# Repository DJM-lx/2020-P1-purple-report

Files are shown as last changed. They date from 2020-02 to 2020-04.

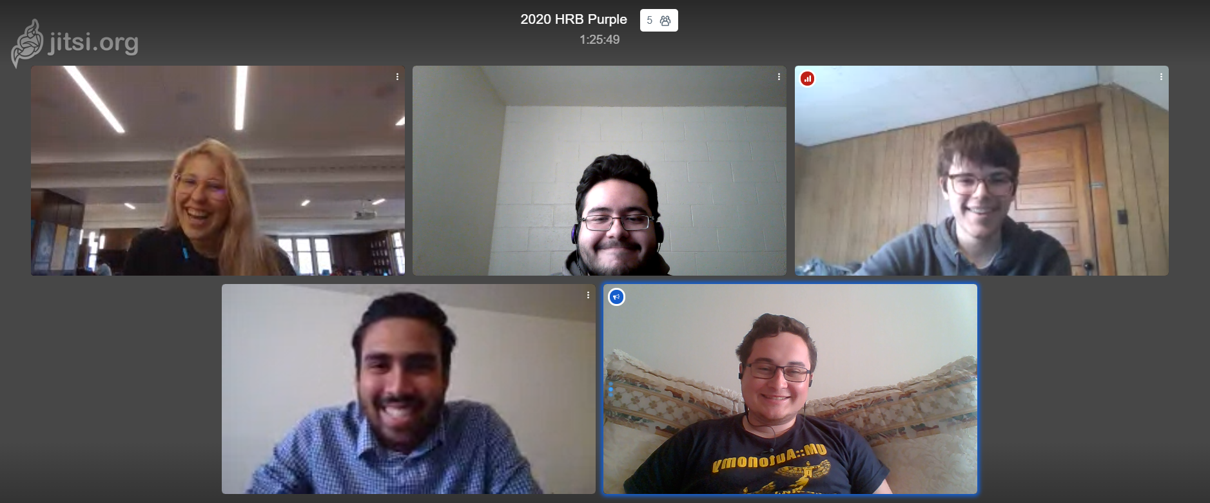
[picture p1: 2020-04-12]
2020-P1_Purple-photo.png

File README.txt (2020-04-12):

This file contains all the necessary resources to reproduce our project for P1-2020

///////////////////////////////////////////////////////////////////////////////

COPYRIGHT.txt - A copyright provision detailing the allowed use of our project resources

2020-P1-Purple-photo.png - photo of the team

2020-P1-purple-team-resources.pdf - a compiled list of resources that guided us in the brainstorming phase

2020-P1-purple-brainstorming.pdf - A PDF of our initial brainstorming presentation given at the beginning of the project cycle

2020-P1-purple-final.pdf - The final report detailing and discussing the results of the project deliverable

src - A folder containing our source code and the details for its use
	-scorpionMasterControl.py - our python script that sets up sensor and waypoint data
	-scorpionPlans.py - our python script for contains plans for autonomous movement
	-scorptionReIX.py - our python script for translating simulated motion to robotic movement
	-scorpionSimIS.py - our python script for simulated motion

howto- A folder containing our how-to documentation to recreate the robot mechanically
	-2020-P1-Purple-howto.pdf the how-to guide to recreate the robot step-by-step
	-3D_Print.zip - the 3d printing files for 3d printed parts we used
	-CadFiles.zip - the cad files for 3d printed parts 
	-Images.zip - the cad images of our robot and robot parts
	-Laser_cutting.zip - files for laser cutting the base

brstm- Source files we used for our brainstorming phase
	- 2019 Red Team's Cad files for their mechanum wheels

////////////////////////////////////////////////

Team Members:

Madi DeVore - devore@umich.edu

David Marsh - djmarsh@umich.edu

Matt Maurer - mlmaurer@umich.edu

Christian Soto - cbsoto@umich.edu

Ragav Subramanian - sragav@umich.edu

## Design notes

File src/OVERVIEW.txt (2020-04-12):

scorpionMasterControl imports from robotSimIX and waypointShared to setup the sensor and waypoint data, sets up the arena

scorpionPlans contains the plans we used to create our autonomous movement

scorpionReIX translated the key presses that moved the simulated robot into moving the motors of the physical robot

scorpionSimIX is the mapped events for the simulated robot. Creates translational movement using the arrow keys and 'A' to start 
autonomous mode

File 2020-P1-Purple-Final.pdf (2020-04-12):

### EECS 464 Project 1

Purple Team: Madi DeVore, David Marsh, Matt Maurer, Christian Soto, Ragav Subramanian April 12, 2020

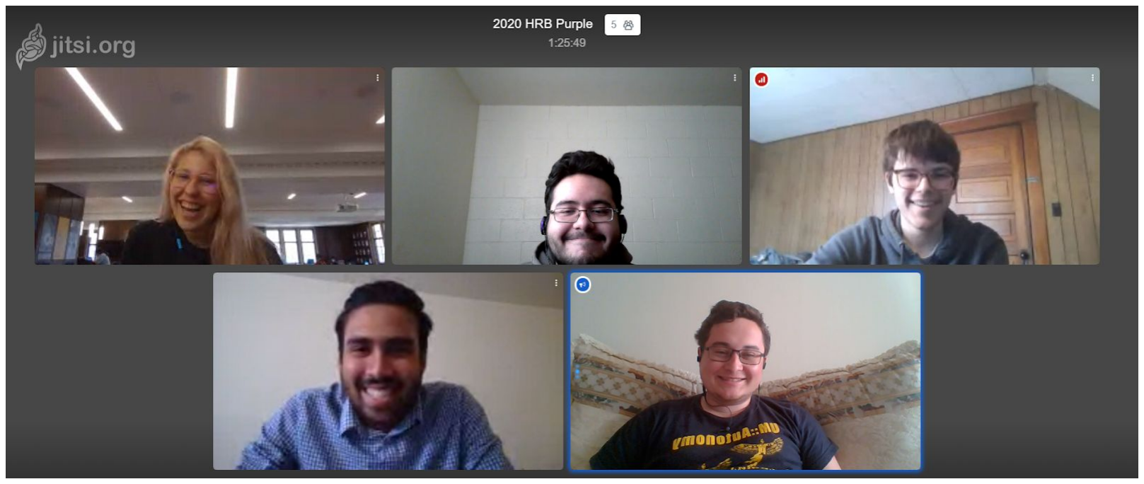
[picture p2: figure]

EECS 464 Project 1

1

Background

3
Project Tasks

3
Arena Layout

3
Research and Design Process

3
Mecanum Wheeled Design 1

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
Moving Turret

5
Final Design

5
Hardware

5
Software

6

P-Day Results

6
Pass/Fail Requirement

6
Overview of Teams performance for each arena

7

Discussions

7
Overall analysis

7
Individual Team Designs

7
Purple

7
Blue

8
Maize

8
Green

9
Red

9
Future Improvements | 10
Hardware | 10
Software | 10
Update moving between waypoints | 10
Modify the recovery plan | 10

### Background

Project Tasks
Our task goals and requirements were listed in the task specifications for Winter 2020 EECS 464 Project 1. Our task was to design and build a physical and simulated robot that could traverse an arbitrarily sized track with arbitrarily placed waypoints while maintaining the orientation of the direction of a mounted laser. In addition, the robot’s movement to and between the waypoints were to be achieved with and without human interference. Due to recent events at the time this project was attempted, any goals and requirements involving the physical robot were considered omitted from the task specifications. The pass-fail criteria for meeting the task goal were as follows:
- Robot stays in the arena, with robot tag within 1m vertically of the floor
- Robot reaches the final waypoint within 15 minutes
- Laser never illuminates in a direction with a negative Y component

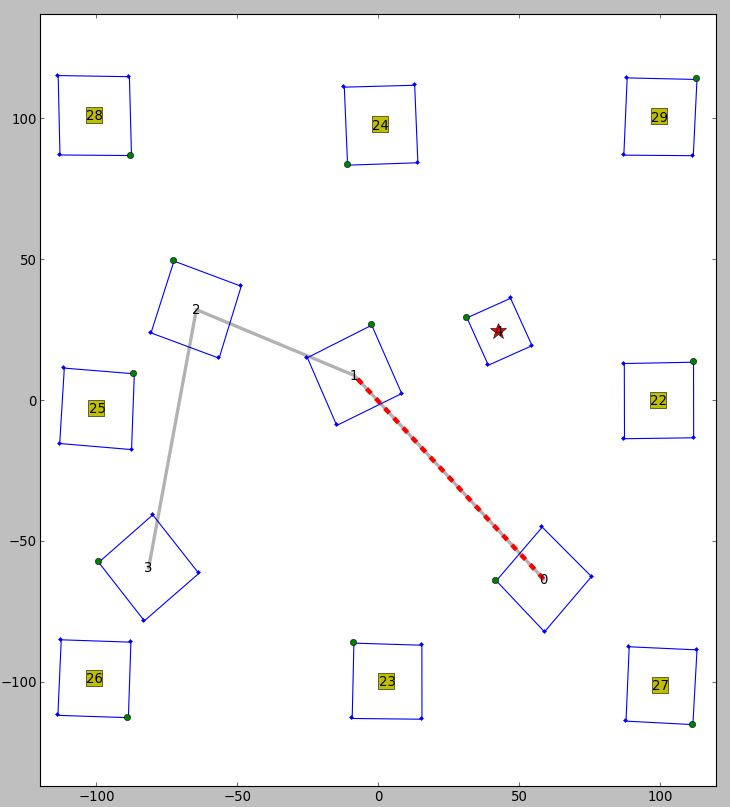
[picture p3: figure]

Arena Layout
The arena in which the robot operates is a 2m x 2m square delineated by 8 barcodes or tags as they’re seen in the virtual modelling. All tags are square and the same size. The waypoints are also modelled using tags and the location of the robot is tracked using its own tag. In order to successfully reach a waypoint the robot’s tag must be within a tag’s radius of the waypoint tag. Since we switched to modelling the arena virtually the physical dimensions are arbitrary as we now use x and y coordinates.

Research and Design Process
Before beginning the construction of the robot, we considered multiple design alternatives. This section describes the three alternatives we showcased in our brainstorming presentation. (https://wiki2.eecs.umich.edu/hrb/index.php/File:2020-P1-purple-brainstorming.pdf)

Mecanum Wheeled Design 1
Design 1 used mecanum wheels similar to 2019 Red Team. (https://wiki2.eecs.umich.edu/hrb/images/1/1a/2019-P1-red-final-GRADED.pdf) We considered using three pairs of mecanum wheels and continuous rotation (CR) modules attached to the bottom of our proposed triangle base. A mecanum wheel, shown in Figure 2, is a wheel that has cylindrically-shaped rollers mounted around its circumference at a 45 degree angle to the axis of rotation. A mecanum wheel has independent motion relative to the others in the system, and the combination of all these different motions can be vectored into cardinal directions relative to the system, shown in Figure 3. A more detailed explanation can be found at Wikipedia’s Mecanum Wheel, (https://en.wikipedia.org/wiki/Mecanum_wheel) and a YouTube demo can be found here. (https://www.youtube.com/watch?v=o-j9TReI1aQ)

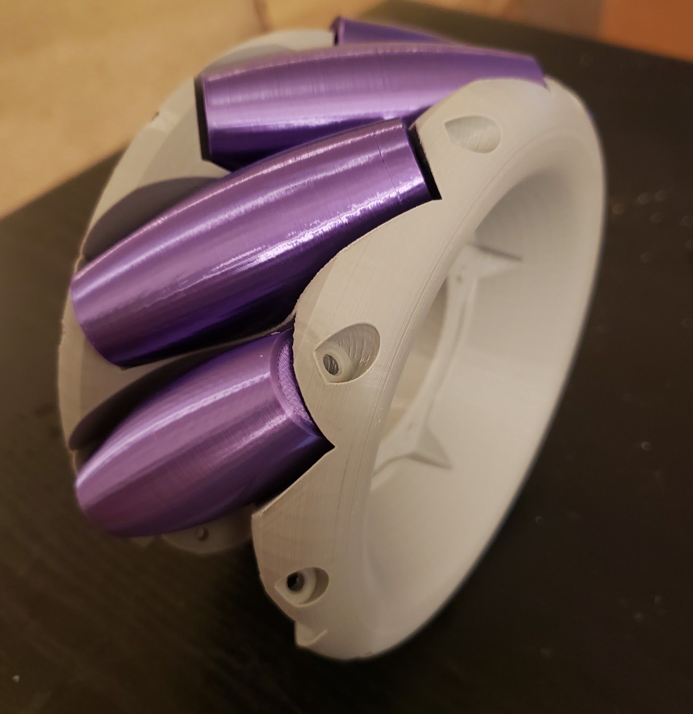
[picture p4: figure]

Wheeled Design 2

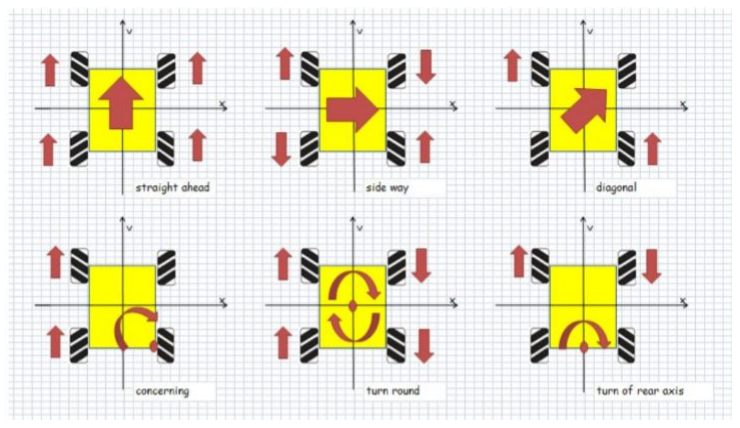
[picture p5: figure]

We considered attaching a U-bracket module to the end of a CR module. A drive wheel attached to the CR module could be lifted off the ground using the U-bracket module, shown in Figure 4. If we had two pairs of motors in this configuration, mounted orthogonal to each other, we could drive anywhere in the plane without rotating the robot. We planned on putting ball castors, shown in Figure 5, on the bottom of the robot so that the base supporting the motor modules could glide in both directions.
We did not end up pursuing castors on the base because we were concerned that the robot would turn on the castors. However we did use the CR module mounted on the end of the U-bracket module for our final design.

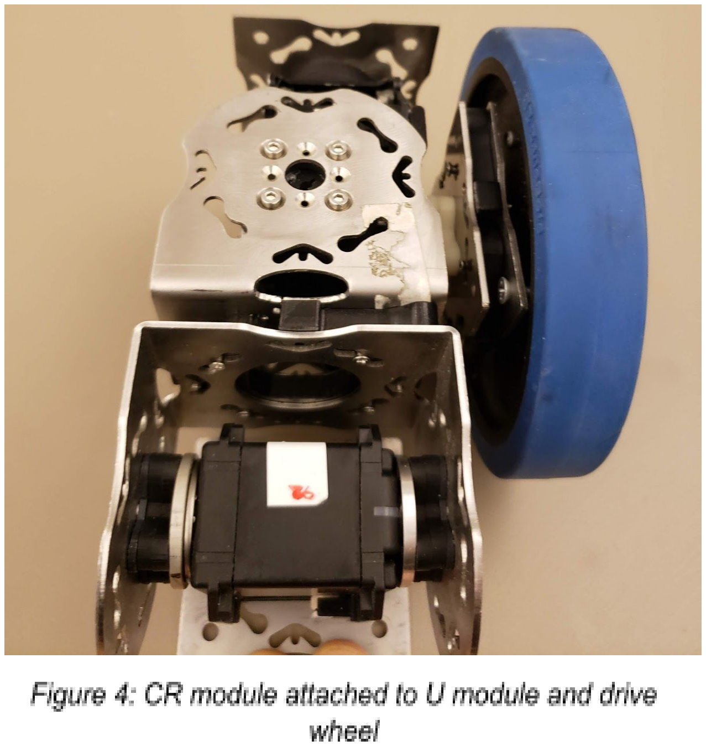
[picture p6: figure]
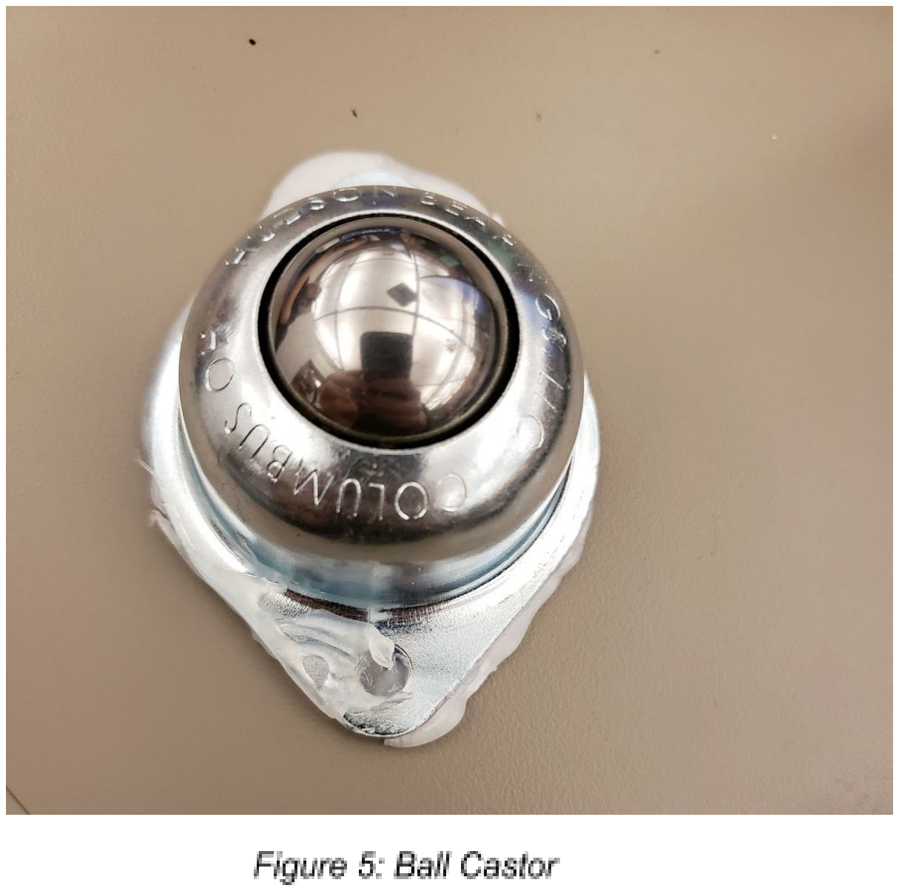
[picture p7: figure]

Moving Turret
This Moving Turret Design was an experimental idea that was not based off of any previous team’s design. The basis of the design was to take a lot of the heavy work off of any software control system for maintaining the turret consistently in the +x-direction. The robot was designed to have a rod that is freely held using bearings through the center of the robot chassis. This central rod would hold the turret on top and have a castor wheel on the bottom. This pivotal rod would allow the turret to remain focused in +x-direction as we pivot the robot to turn, the rod would not rotate due to the low-friction skateball bearings that would connect the central rod to the chassis. However, we did not pursue this idea as it was quite experimental and if the frictionless effect of the bearings did not hold up, the mechanical design would be for nothing.

Final Design

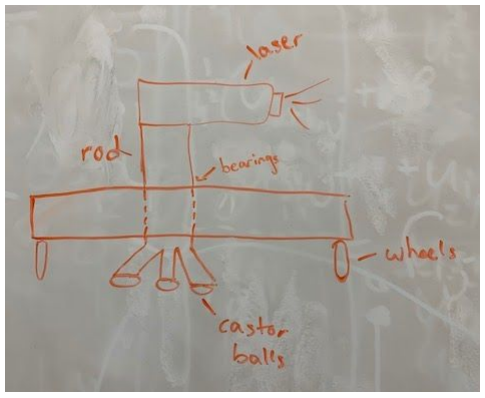
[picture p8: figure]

The project moved to a simulation after completing demos 1 and 2 due to the cancelation of in-person lectures.

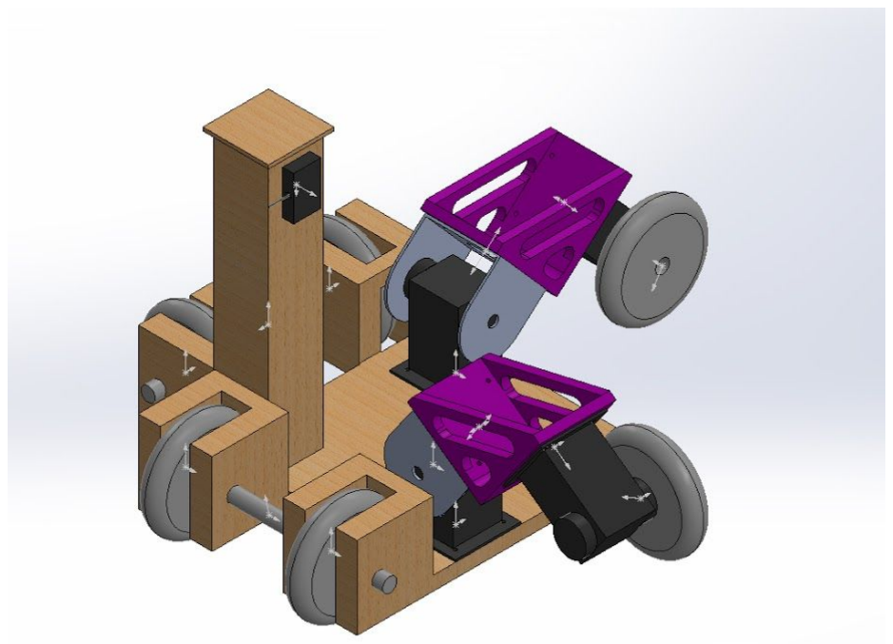
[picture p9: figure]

Hardware
Our final design was essentially two tricycles in orthogonal
directions. By lowering one of the two U-bracket modules, we could tip the base of the robot until only the three wheels oriented in that direction were touching the ground. Then, the robot moved in a straight line by rotating a CR module attached to the end of the U-bracket module.
The robot was able to move continuously in +- X and +- Y with minimal rotation in the z direction. The physical robot was abandoned before we were able to gather quantitative data.

Software
The software we created can be found in the Purple Team How-To Directory. (https://wiki2.eecs.umich.edu/hrb/index.php/File:2020-P1-purple-howto.zip) We chose to use a Python program to control the simulation, utilizing the robotSimIX library provided and a scorpionSimIX file of our own. Our control program mimicked the translational motion of the mobot we designed allowing it to go left, right, forwards, and backwards without turning. When in manual mode the program created an event handling system to handle keyboard presses as shown in Table 1 so that it would move when the corresponding buttons were pressed. Upon pressing ‘A’ the software would start the autonomous plan which would calculate the distance from the first waypoint to the next and attempt to move that distance in the x and y directions. If the waypoint was missed then it would spiral from where the simulated robot moved to until it reached the next waypoint. The worst case of the spiral feature would be to extend the spiral to spanning the entire arena.
Key | Left Arrow | Right Arrow | Up Arrow | Down Arrow | ‘A’
Simulated Action | Move left | Move right | Move forward | Move backwards | Start autonomous mode

### P-Day Results

P-day consisted of 10 different arenas that each team attempted to complete within the time constraints of the class period. This averaged to about 10 minutes per arena. Each arena had a different seed that would randomize the waypoints’ locations.

Pass/Fail Requirement
Due to the project moving to a virtual format the pass/fail requirement was changed. The conditions relating to the physical movement of the robot were dropped and now each team needed to reach the final waypoint in under 15 minutes. Each team completed the pass/fail requirement during P-Day and were able to submit multiple runs with completed arenas. Most teams were able to complete all 10 arenas, but Purple and Maize ran into technical difficulties and were only able to submit 5 arenas.

Overview of Teams performance for each arena
Each team had the capability to move their robot manually to the final waypoint. Maize and Red teams chose to manually move their robots and not attempt autonomous mode. Green team attempted autonomous mode but failed and then drove their robot manually to the final waypoint. Purple team attempted autonomous mode but ran into problems with correctly generating the randomized arena. Purple team managed to successfully complete a couple of arenas in autonomous mode but did not have enough time to attempt all arenas. Blue team was the most successful attempting autonomous mode for each arena and managed to hit all of the waypoints. A breakdown of how each team performed in each arena is given in Table 2.

Team | Arena 0 | Arena 1 | Arena 2 | Arena 3 | Arena 4 | Arena 5 | Arena 6 | Arena 7 | Arena 8 | Arena 9
Maize | ---- | 2/3 | M | ---- | ---- | M | ----- | M | M | -----
Red | M | M | M | M | M | M | M | M | M | M
Green | AA | AA | AA | AA | AA | AA | AA | AA | AA | AA
Purple | AA | ------ | AS | AS | AS | ----- | AS | ----- | ----- | ------
Blue | AS | AS | AS | AS | AS | AS | AS | AS | AS | AS

Maize team had problems getting their robot to find the first waypoint, their missing trials corresponded to the runs where they were unable to locate the first waypoint and got stuck. Maize team was able to successfully reach 2 of 3 waypoints in Arena 1. Purple team’s missing trials were from running out of time during P-Day and also from running the arenas before realizing that we were incorrectly randomizing the waypoints. The data produced from those runs correspond to the same waypoints given to us to practice with.

### Discussions

Overall analysis
Blue team was the only team to successfully use autonomous mode for every arena. Green and Purple also attempted autonomous mode but were either unsuccessful or sometimes successful. Maize and Red used manual mode for each arena.

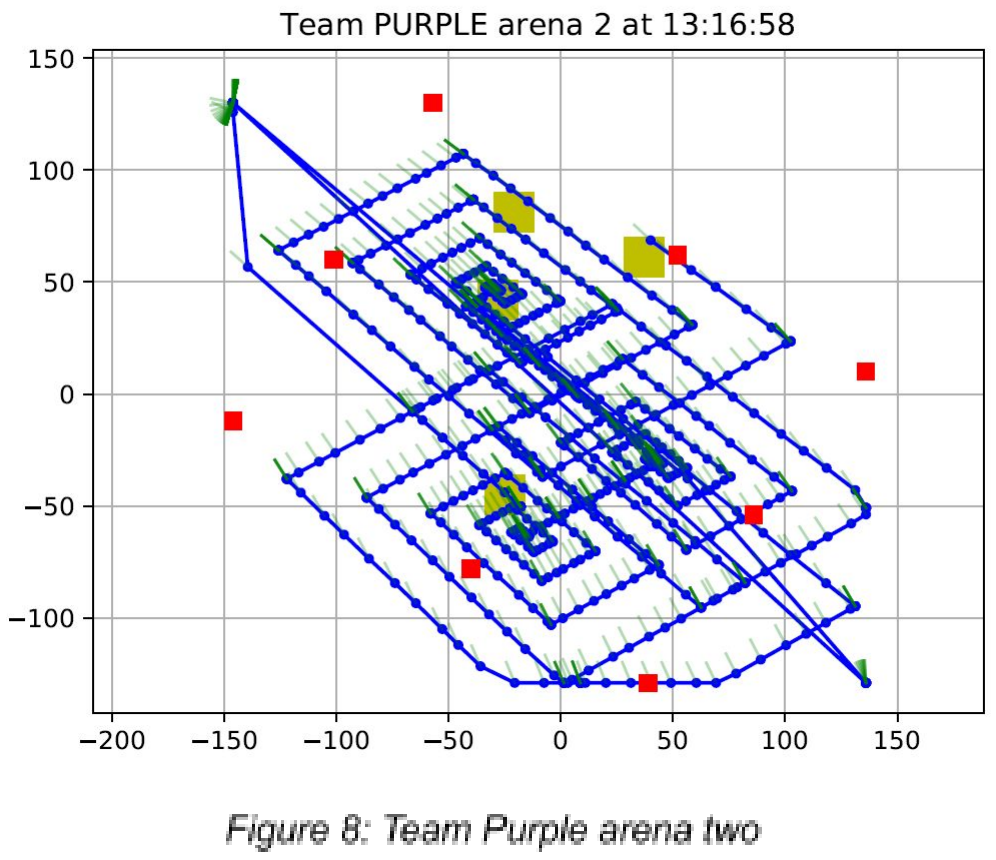
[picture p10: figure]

Individual Team Designs

Purple
Once we fixed the problem with our code not correctly generating new arenas we had successful autonomous trials. Since it took us about half an hour to work out why our code wasn’t functioning and about 20 minutes more to debug the problem we did not have enough time to run all the arenas. This bug came up because we created our own class that inherited some of Professor Revzen’s code, but it was not updated when new software updates were released. In the arenas we did have time to redo we had originally run them without regenerating new waypoints so they all had waypoints corresponding to those of the practice arena. Our simulation moved translationally. Once we drove to the first waypoint we would assume that the waypoint was our starting location and would calculate what y and x distances we would need to travel in order to reach the next waypoint. If the robot missed the waypoint it would spiral until it hit the next waypoint. In the visualization generated for arena 2 we missed the waypoint three times so there are three different spirals.

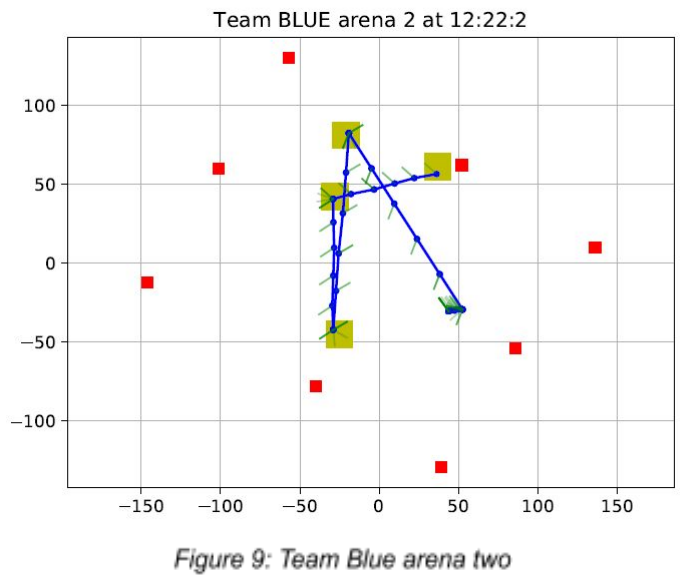
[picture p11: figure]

Blue
Blue team had a working autonomous program. They were able to reach all waypoints in all maps. Their program used a particle filter and attempted to drive directly to each waypoint. In the event that the robot missed the waypoint, it entered a scanning recovery procedure. They were able to finish 5 of the 9 maps directly without using the recovery procedure.

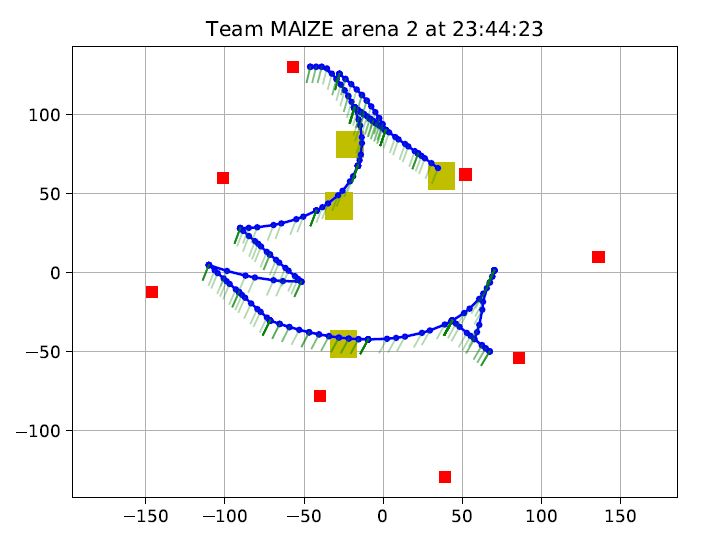
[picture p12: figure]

Maize
Maize team had computer hardware issues. They were unable to stream video and run the simulation smoothly at the same time. They drove manually to the waypoints. Their control system relied on needing to constantly reorient the arena. The more their simulated robot rotated the less they were able to control it. They used a spiralling recovery strategy that would swing the “arm” of the robot while driving it forwards and backwards to form a spiral.

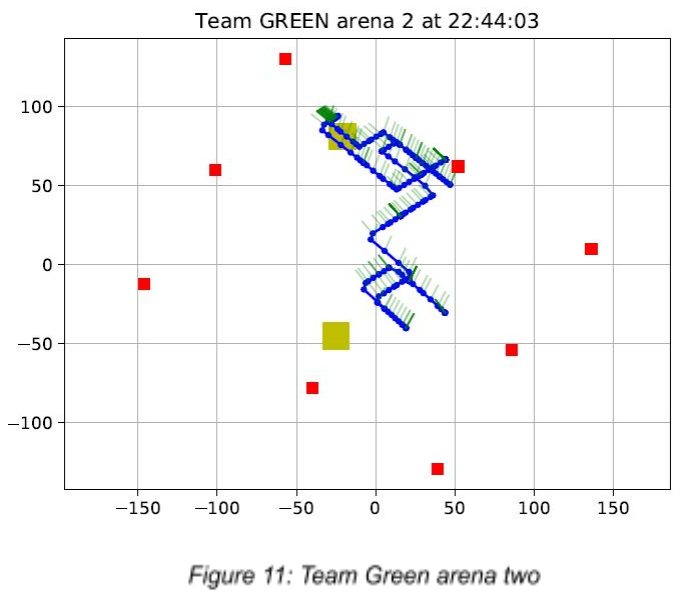
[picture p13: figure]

Green
Green team’s autonomy did not work. They drove to the waypoints manually. Their attempt at autonomous mode resulted in their robot veering off in the opposite direction of the waypoint and continuing indefinitely. Their strategy for recovering their robot during autonomous mode was to keep a history of their movements and backtrack if it missed the waypoint.

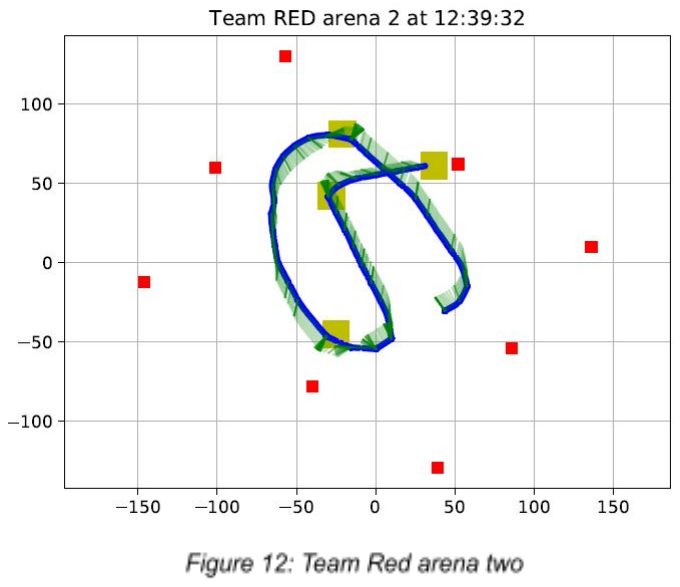
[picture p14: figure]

Red
Red team had their laser pointer pointing in the wrong direction. They drove to all the waypoints manually. They did not attempt to do autonomous mode and had no planned recovery strategy if their robot was to go off course. Their movement used a continuous position estimation by using a particle filter. Their simulation was able to rotate towards the direction they wanted to move and then advance in a line towards it.

Future Improvements

Hardware
The passive wheels on our robot were able to rotate independently from each other because they were both free on the axle. If the passive wheels were fixed to the axle and instead the axle spinned freely it could prevent the robot from rotating.

Software

Update moving between waypoints
Our robot moved in consistent steps when in manual mode, but when run in autonomous mode we had trouble calculating how many steps to use in each direction to reach our goal. Often the robot would overshoot or not move far enough in the x and y directions and would have to resort to spiralling to find the next waypoint. In the future we could improve our software design by making the movement between waypoints more precise and relying less on spiralling in order to reach the next waypoint.

Modify the recovery plan
Our recovery plan would be to just have it spiral until it reached the goal. In order to make this more effective we could add in counters to help us keep track of if we were more likely to over or undershoot or goal. Using this we could either backtrack or take an additional step before we start the spiral so that it wouldn’t need to spiral for very long. Additionally, a smaller step size might help prevent the robot from overshooting waypoints.

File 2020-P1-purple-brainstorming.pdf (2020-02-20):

# P1 - Brainstorming

## Purple Team: Madi DeVore, David Marsh, Matt Maurer, Christian Soto, Ragav Subramanian

# Overview

Each robot is required to reach a sequence of waypoints in a specified order while keeping a laser pointer oriented along the positive Y axis. Position of the robot, waypoints, and laser is given by a computer vision system provided by the instructor.

# Pass/Fail Criteria

1. Robot stays in the arena, with robot tag within 1m vertically of the floor
2. Robot reaches the final waypoint within 15 minutes
3. Laser never illuminates in a direction with a negative Y component

* if a team feels they might not meet the pass/fail criteria they may manually drive their robot to the final waypoint and forfeit the competition

# Design 1 - Mecanum Wheeled

This design utilizes omnidirectional mecanum wheels for the movement of the robot. It would have three rotational dynamixel modules mounted to the bottom surface of the chassis, and each module would rotate a mecanum wheel. The laser would be mounted in a constant orientation.

The robot and laser would face the same direction during the task, and different rotations of the dynamixel modules would result in the sufficient x- and y-motion without needing to rotate the robot.

Another variation of this design would be to use four mecanum wheels (two sets of mirrored pairs) with a similar design structure.

# Design 1 - Mecanum Wheeled

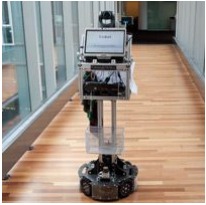
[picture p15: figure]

PROS:

- Body points in same direction
- 2019 Red Team (https://wiki2.eecs.umich.edu/hrb/images/1/1a/2019-P1-red-final-GRADED.pdf) made 3 mecanum wheeled robot that we can use as a basis

CONS:

- Mecanum wheel is difficult to build
- Slightly complex wheel movement

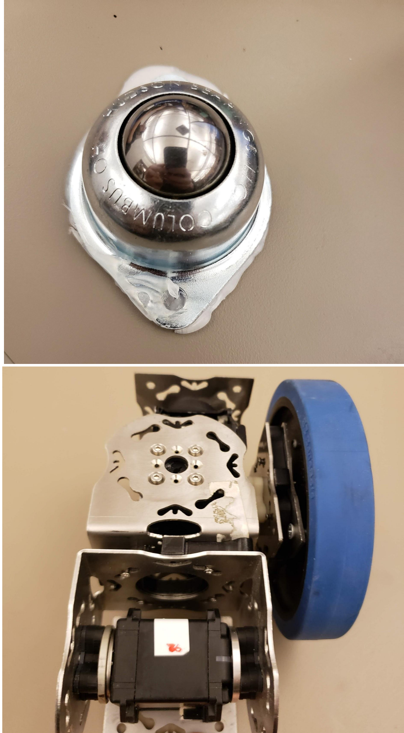
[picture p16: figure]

# Design 2

Rectangular base that slides on 4 castor balls

To move in Y:

A u-bar module mounted on the back of the base lowers two wheels driven by a continuous module

To move in X:

An identical mechanism is mounted on the left or right of the base

# Design 2:Pros and Cons

Pros:

- Separate systems for x and y motion help with holonomic motion

Cons:

- Asymmetrical weight distribution

# Design 3: Moving Turret

Two wheel based tower

Consists of laser on servo placed at top of tower

Laser will maintain aiming at the +y - direction and will adjust when turning using a PID controller

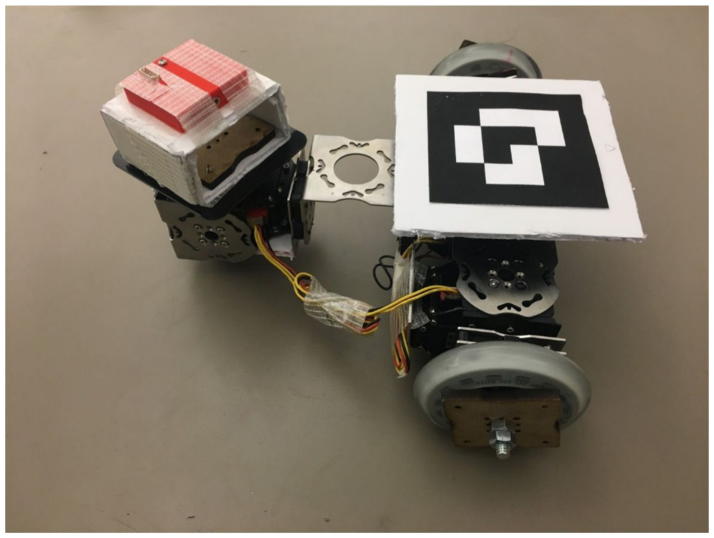
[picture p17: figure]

Inspired by 2018 Green team except laser mounted on top

# Design 3: Pros and Cons

Pros:

- Simple Mechanical Design
- Easy Mechanical Construction

Cons:

- May be challenging to work with PID controller
- Servo displacement error compounds

# Design 3.1: Moving Turret + standalone laser

Iteration of Moving Turret

Replace mounted servo with the laser on a rod that extends through chassis and stands on 3 legs with caster balls

-Minimum Friction bearings used to prevent rotation of servo mount

Lubricant may be used to ensure little to no friction between laser stand and chassis

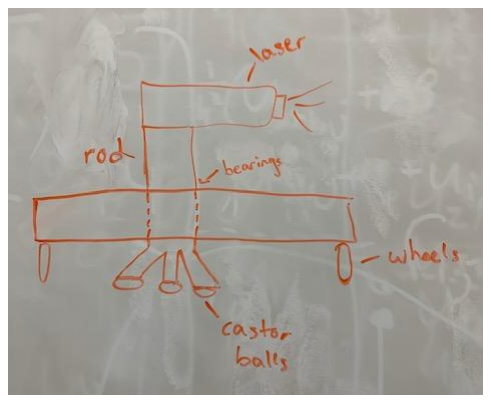
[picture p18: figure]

# Design 3.1: Pros and Cons

Pros:

- Simple Mechanical Movement
- Easy Mechanical Construction

Cons:

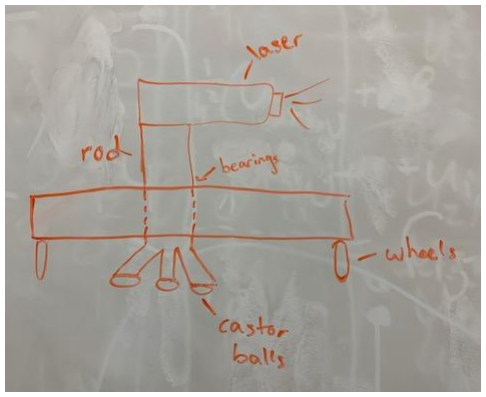
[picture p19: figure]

- Difficult to get rod to remain in place and “frictionless” bearing
- No control scheme

# Team Skills and Projected Roles

Madi: Mechanical design and testing

David: Mechanical design and construction

Matt: Prototyping and construction

Christian: Programming, Simulated Robotics

Ragav: Programming and Mechanical construction

# Workplan

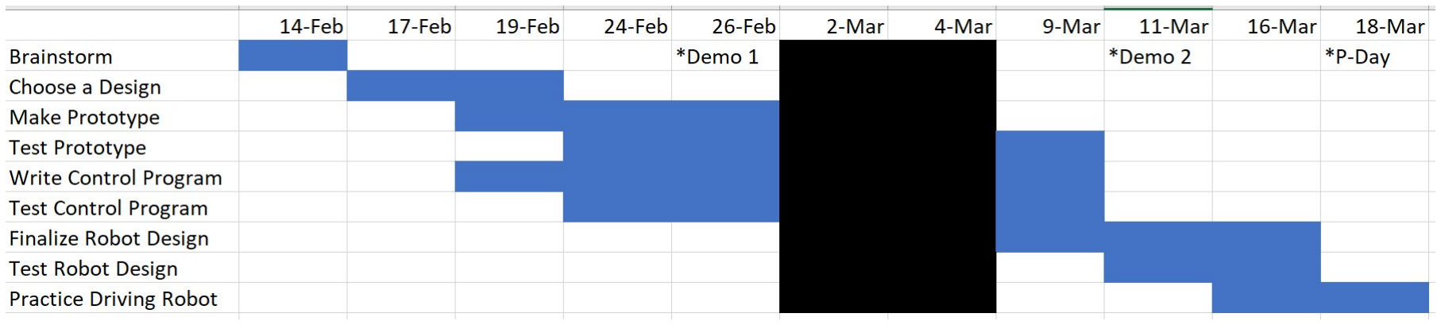
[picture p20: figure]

# Risks and Mitigation

- Navigation
- If we use the mecanum wheels we need to be able to guarantee that they will work consistently and not have problems with friction due to the carpet
- Complexity
- The more complex our design the higher the chance that small variances in performance can appear causing errors in positioning
- Time Management
- Since we have to factor spring break into our project cycle we need to be on top of our time management in order to complete Demo #1 and #2 before and after the break
- Parts
- Since we may need parts to be ordered, it is crucial we have enough parts and spares to complete the design

# Resources

2019 P1 Red Team Final Report (https://wiki2.eecs.umich.edu/hrb/images/1/1a/2019-P1-red-final-GRADED.pdf)

2017 Green Team P1 (https://wiki2.eecs.umich.edu/hrb/index.php/File:2017-P1-Green-report.zip)

2018 Green Team P1 (https://wiki2.eecs.umich.edu/hrb/index.php/File:2018-P1-green-report.zip)

Frictionless bearings (https://www.popularmechanics.com/technology/gear/a15603/super-efficient-greaseless-bearings/)

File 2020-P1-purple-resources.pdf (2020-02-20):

P1 Purple Brainstorming Resources

2019 Red Team P1 (https://wiki2.eecs.umich.edu/hrb/images/1/1a/2019-P1-red-final-GRADED.pdf)
2019 Red Team’s robot utilizes a three mecanum wheeled robot. The layout of the wheels is in a triangle orientation. With different combinations of the dynamixel modules rotating, they were able to achieve x- and y-motion without needing to rotate their robot. By using their report and design files as a resource, we would like to make a similar robot using either a three- or four-wheeled setup.

2017 Green Team P1 (https://wiki2.eecs.umich.edu/hrb/index.php/File:2017-P1-Green-report.zip)
2017 Green Team’s robot utilizes a track that spans the entire x axis of the field. The track is on wheels that move the entire track along the y axis. We used their design as inspiration for our first design idea. This strategy is useful because it maintains holonomic motion, which will be important for maintaining the direction of the laser pointer. This design could be problematic because you need to store where the robot is located in relation to the field and if the coordinates get off you could get lost.

2018 Green Team P1 (https://wiki2.eecs.umich.edu/hrb/index.php/File:2018-P1-green-report.zip)
2018 Green Team’s robot uses a two wheel based tower. We were inspired by their design and applied the idea to design 4. This design is useful since we have their files as a resource and all we need to do is add a laser and improve upon their design. Design 4.1 is an extension of the idea of a tower mounted laser.
Frictionless bearings (https://www.popularmechanics.com/technology/gear/a15603/super-efficient-greaseless-bearings/)
These bearings a new way of keeping the balls inside of bearings separated. Traditional ball bearings use a cage device to help keep the balls an equal distance apart from each other. This introduces extra friction between the ball and the cage, so grease is added to assist in more frictionless movement. These new bearings do not use a cage, but rather there are divots and bumps added to the bearing to help keep the balls apart from each other. This allows for less friction to take place and for a bearing that is more efficient. We can use these types of bearings or concepts of them to aid in our rotating parts of our robot.

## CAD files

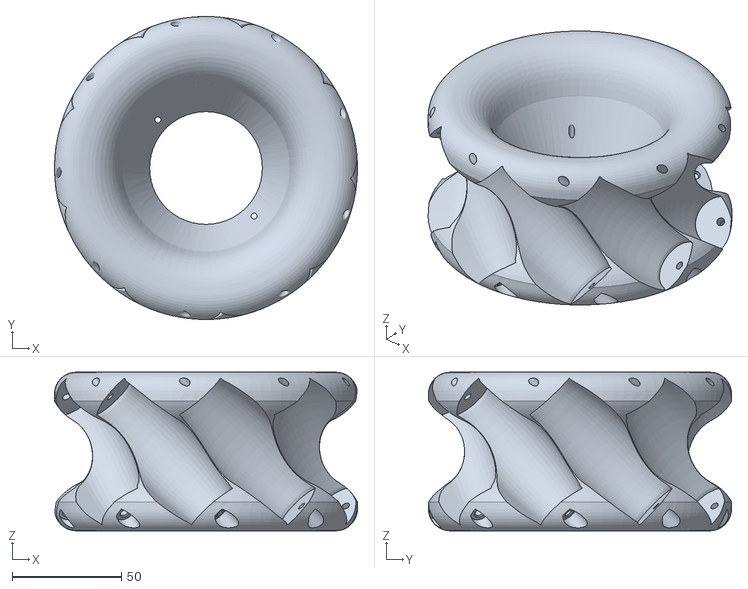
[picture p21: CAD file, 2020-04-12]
brstm/Mecanum_Hub.STL
138.6 x 138.6 x 72.6

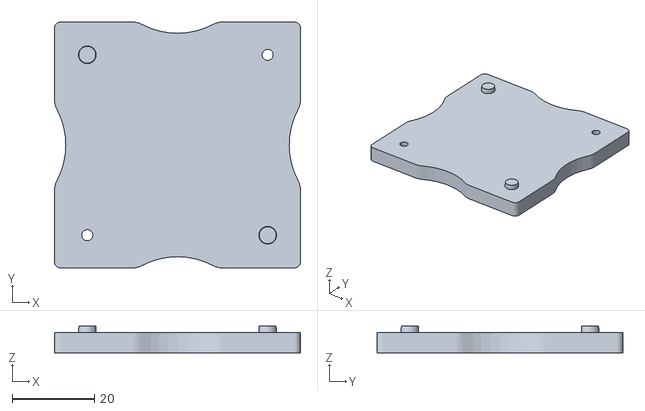
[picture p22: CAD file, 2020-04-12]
brstm/Wheel Spacer.STL
60.0 x 60.0 x 6.55

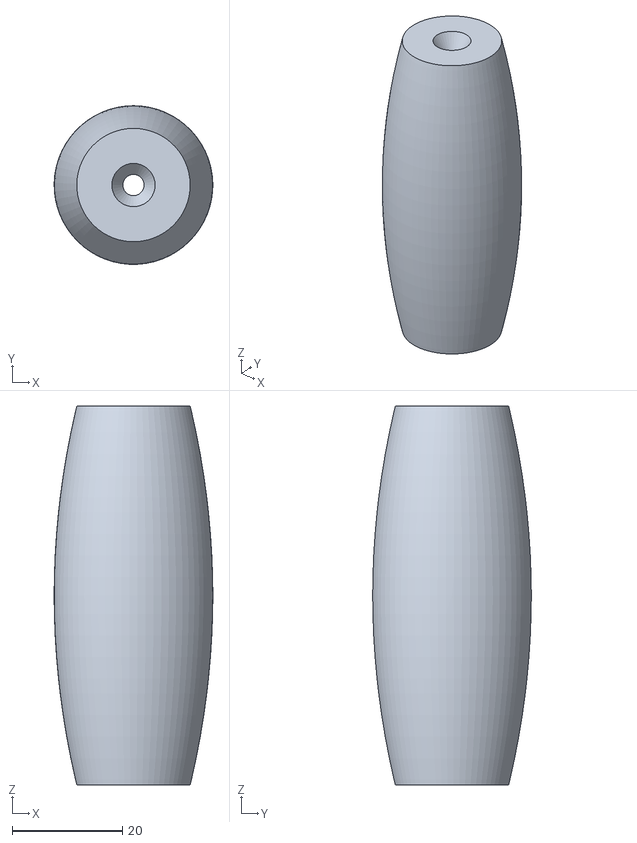
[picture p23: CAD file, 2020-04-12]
brstm/Mecanum_Roller.STL
28.8 x 28.8 x 68.8

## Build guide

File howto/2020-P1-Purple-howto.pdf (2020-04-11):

# Winter 2020 P1 Purple Team

Ragav Subramanian, Madi Devore, Christian Soto, Matt Maurer, David Marsh

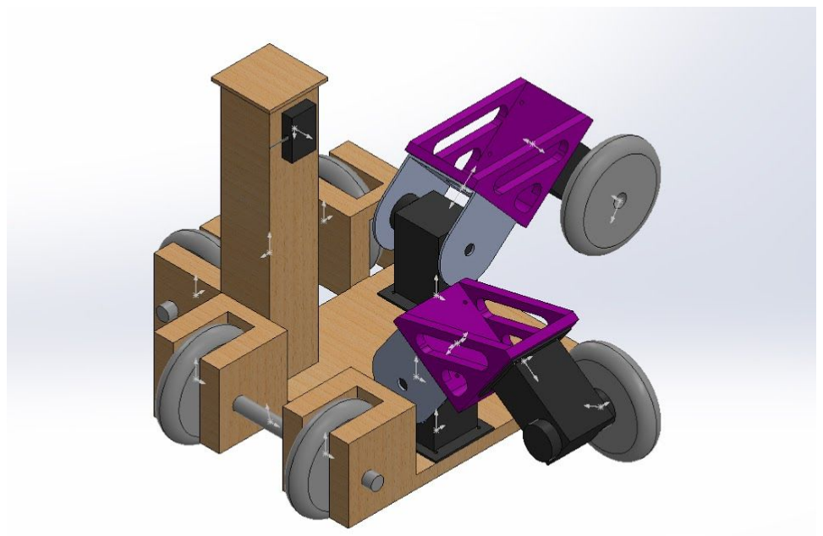
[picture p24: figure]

# Robot Assembly:

## Base

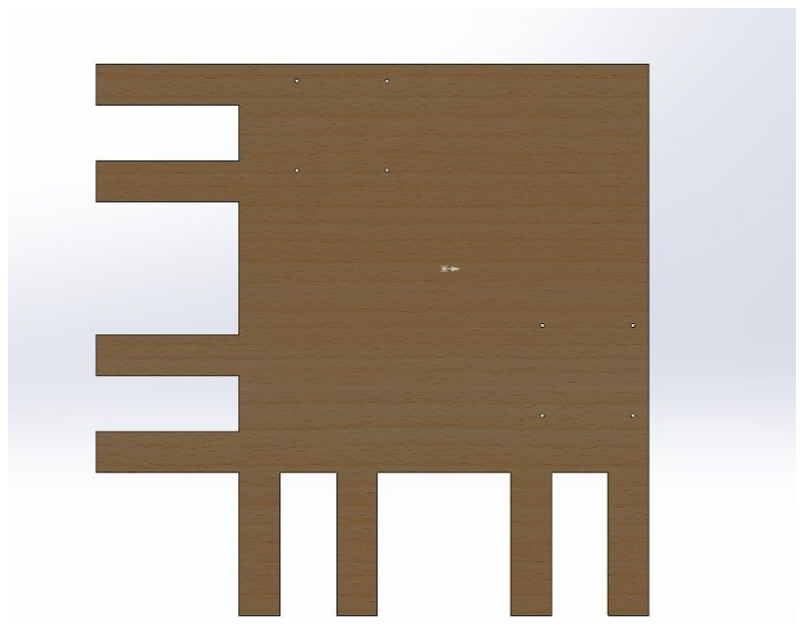
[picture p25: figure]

Laser cut the base from Base1.DWG out of ½” foam core. Line up two tailplates and two plastic spacers over the pilot holes in the base. Fasten with two drywall screws and a wood spacer for each tailplate.
By hand, cut a 45 degree bevel from each side of the 4 forks protruding from the base. The cut should go from the inside top edge of the fork to the outside bottom edge.

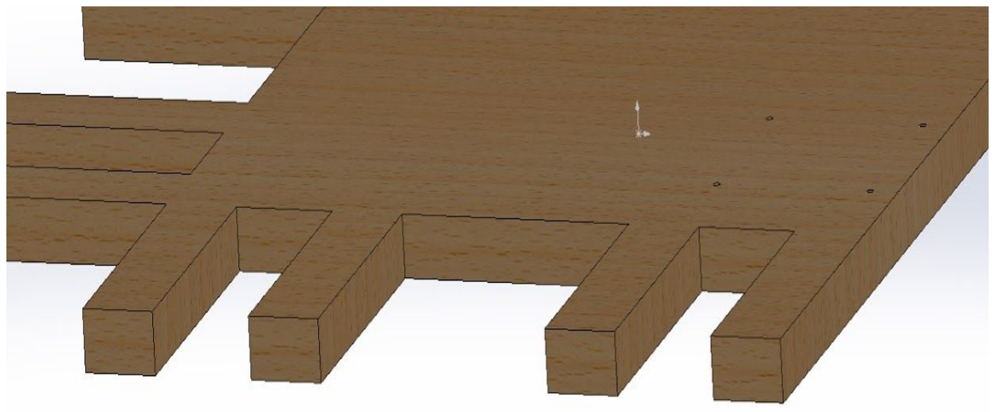
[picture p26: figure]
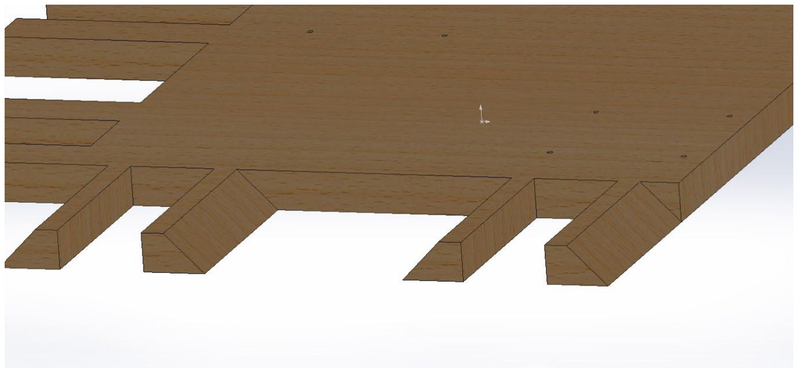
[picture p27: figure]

Before Cut | After 45° Cut

## Passive Wheels

### Wheel Wells (4):

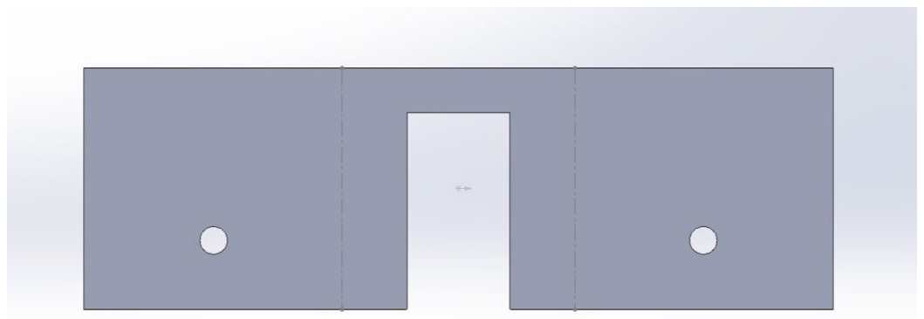
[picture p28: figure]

The wheel wells are laser cut with the base in Base1.DWG. By hand, cut out a channel on either side of the partial cuts so that the piece can fold 90 degrees. The cut should be on the inside of the fold.
Hand cut a 45 degree bevel into the bottom of each side of the wheel well so that it will sit flush with the hand cut bevel on the base.
Using hot glue in the two seams, fold the two corners so that a 90 degree angle is formed. Add tape around corners to strengthen the seam.

Repeat for all 4 wheel wells.

### Axle Assembly (2):

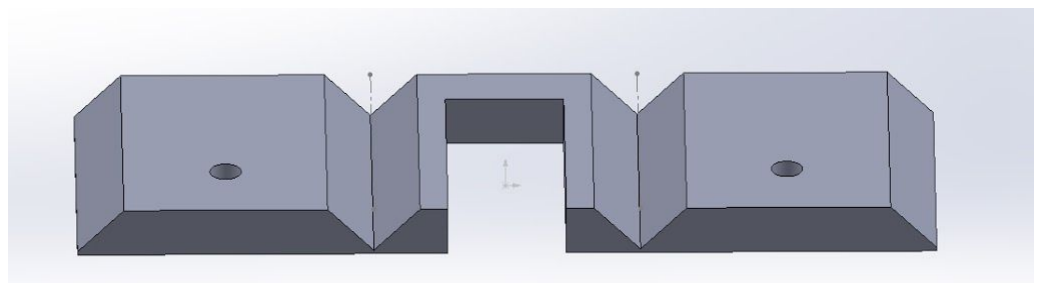
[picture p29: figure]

Take a 5/16” threaded rod and add components in this order from left to right:

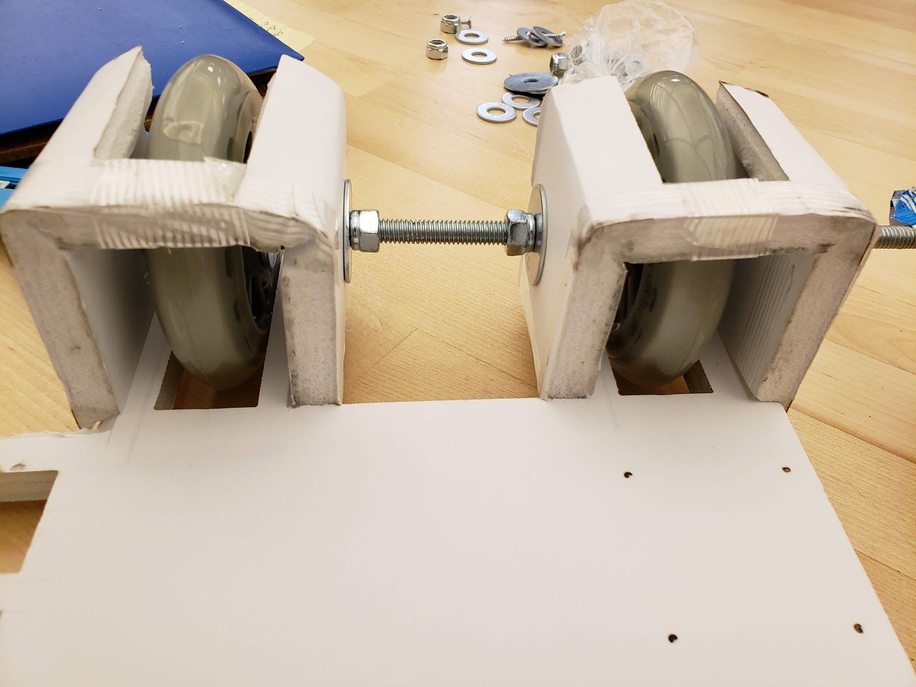
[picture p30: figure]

1. Wheel 1
a. 5/16” lock nut
b. 5/16” fender washer
c. left side of wheel well 1
d. 5/16” lock nut
e. 5/16” washer
f. razor scooter wheel
g. 5/16” Washer
h. 5/16” lock nut
i. right side of wheel well 1
j. 5/16” fender washer
k. 5/16” lock nut

2. Wheel 2
a. 5/16” lock nut
b. 5/16” fender washer
c. left side of wheel well 2
d. 5/16” lock nut
e. 5/16” washer
f. razor scooter wheel
g. 5/16” Washer
h. 5/16” lock nut
i. right side of wheel well 2
j. 5/16” fender washer
k. 5/16” lock nut

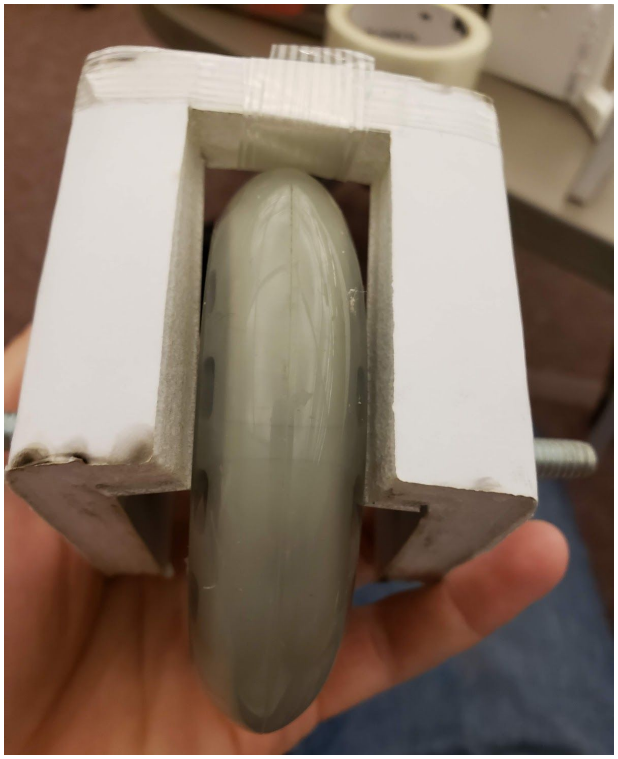
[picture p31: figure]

This is a lengthy process because all lock nuts need to be threaded down the rod. The fender washers should gently press on the outside of the foamcore. The lock nuts inside the wheel wells are for aligning the wheels.

Continue threading the lock nuts until the wheel wells line up with the forks in the base and the wheels are centered in the wheel wells.

Attach the wheel wells to the base with tape and hot glue.

Repeat for the second axle assembly.

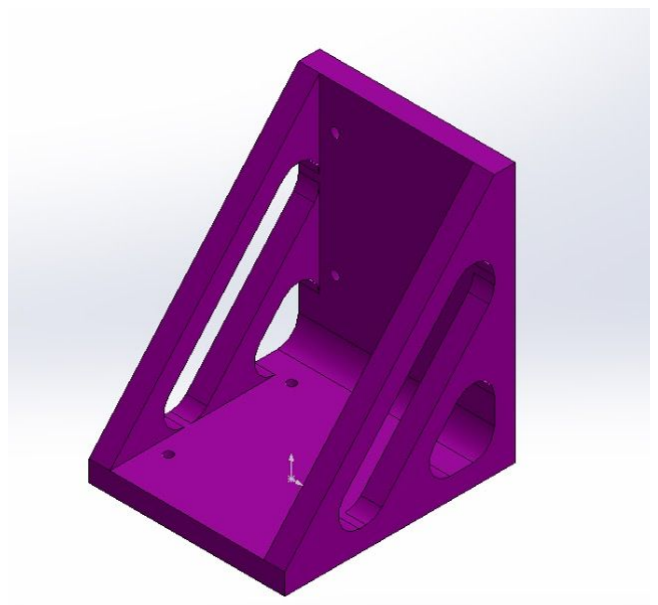
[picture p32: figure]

## Drive wheels (2):

Attach the rotating tailplate of a cr dynamixel module to a large wooden wheel using a modlock. <ADD MORE DETAIL>

3D print RightAngle3.stl Pla with around a 20% infil. This part is used to attach the servo motor and the rotational motor together, but it allows the drive arm to lift the edge of the robot so only the wheels facing the intended direction of motion touch the surface.

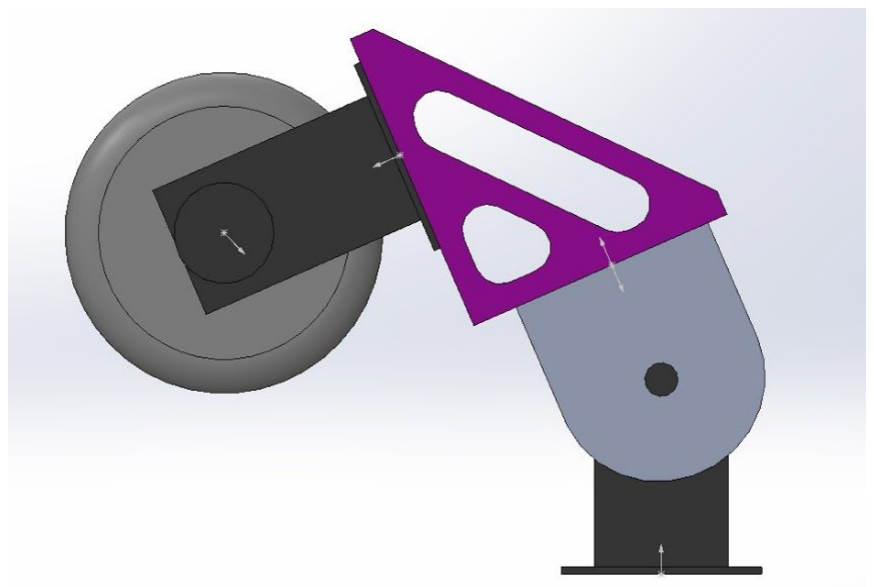
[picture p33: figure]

Attach the bottom tailplate of the cr dynamixel module to a tailplate on the 3d printed joint using a modlock.

Attach the bottom tailplate of a u-bar dynamixel module to the other tailplate on the 3d printed joint using a modlock.

Attach the top of the u bracket to a tailplate on the base using a modlock. The 3d printed joint is mounted correctly if the wheel touches the ground before the motor.

Repeat for the second drive wheel. Link all the motors together with cable jumpers.

# Tower:

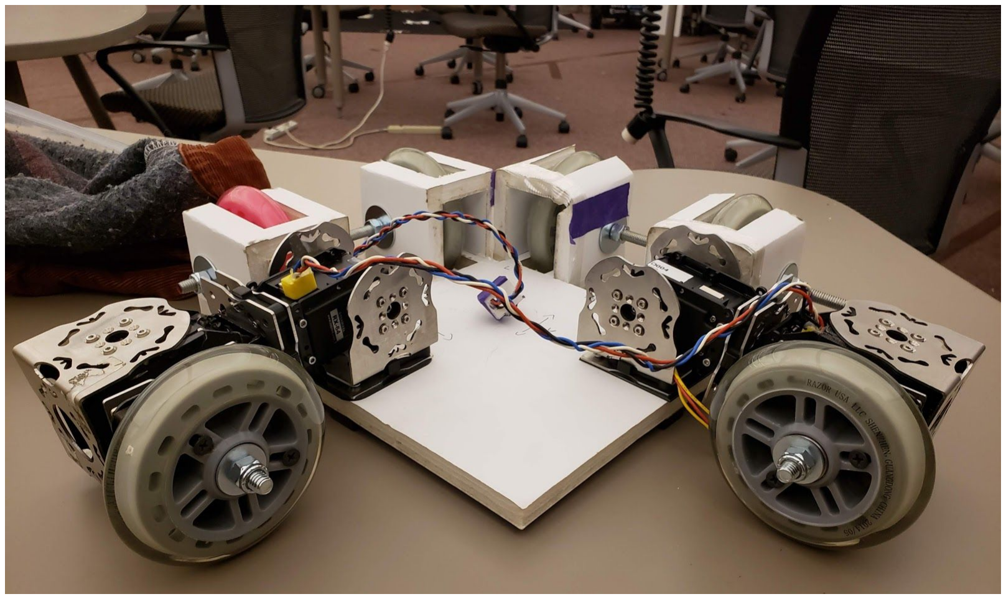
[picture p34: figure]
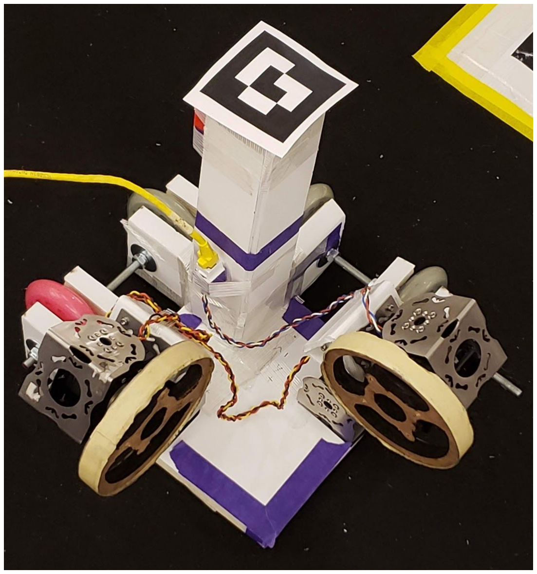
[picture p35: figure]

Cut a 2x10cm strip of foamcore and tape it in the corner created by the two middle wheel wells. This is a spacer to prevent the wheels from touching the tower.
Build a 5x5x30cm square prism out of ⅜” foamcore. Tape the prism to the spacer and to the base.
Lower the wheel that moves the robot in the direction of the whiteboard to its drive position. Use a level to mount the laser so that the beam is level when the wheel in the direction of the whiteboard is engaged. Connect the laser to a motor with the cable jumpers.
Tape the robot april tag to the top of the tower. Tape the cable with the rj45 connector to the middle of the tower.

# Software

The software is broken up into four parts: scorpionMasterControl.py, scorpionPlans.py, scorpionReIX.py, and scorpionSimIX.py. The script scorpionMasterControl.py is the main which calls upon functions from the files. The scorpionReIX.py and scorpionSimIX.py scripts are identical at a higher level but implementation-wise, one affects the real-world robot and the other the simulated robot respectively. The scorpionPlans.py script has the Move and Autonomous plans that work for both scorpionReIX.py scorpionSimIX.py. In essence, we call these high level functions that allow us to abstract away the autonomous and manual specific implementation.

The simulated robot can move in both directions in pure vertical and pure horizontal directions. This is to reflect the physical design of our robot which moved in this way except for slight turns caused by noise.

Our autonomous algorithm moves in a spiral until the robot hits the next waypoint. Once it hits the waypoint it takes the x and y distance from the first and next waypoints and applies an equivalent amount of movement to the robot in the direction from the first waypoint to the next. If it hits the waypoint then the current waypoint is updated and it spirals again repeating the process but trying to find the current next waypoint. If it misses the waypoint the robot will move in a spiral until it hits it.

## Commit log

2020-04-12 updated brstm, and src files
    [Mecanum_Hub.STL, Mecanum_Roller.STL, Wheel Spacer.STL]
2020-04-12 Update 3D_Print.zip with mecanum wheel files
